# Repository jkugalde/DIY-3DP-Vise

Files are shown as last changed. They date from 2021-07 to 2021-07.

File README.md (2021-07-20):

# DIY 3DP Vise

[][cc-by-sa]

It is a small vise

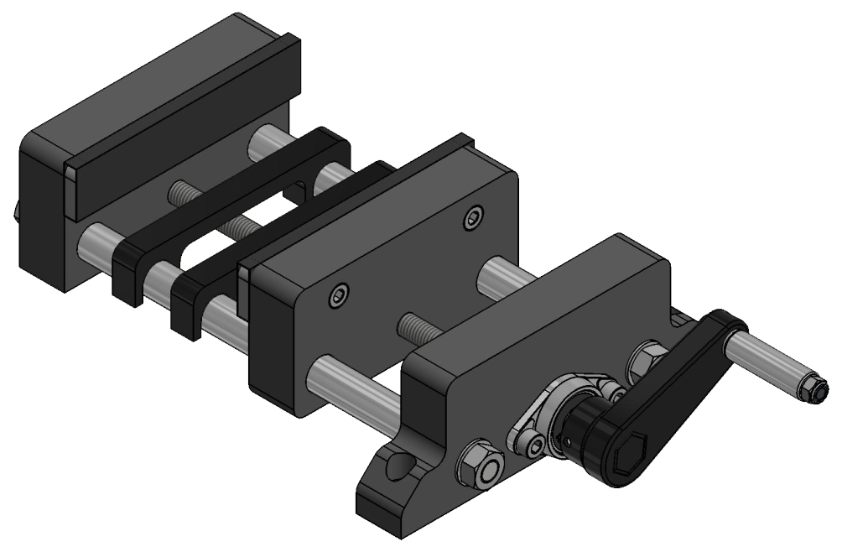
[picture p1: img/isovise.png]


## Features

- Cheap
- 115 mm opening
- Removable handle
- Fixed size, not affected by the movement of the jaw
- Rubber surface jaw

## How to build it

- [LIST](parts.md) of parts, pieces and tools. 
- [CAD files](parts/).
- [Assembly instructions](assembly.md)

## Future work

- A more comfortable handle, to fit the whole hand.
- Assembly guide with images.

# License

[][cc-by-sa]

This work is published under the license [Creative Commons Attribution 4.0 International
License][cc-by-sa].

[cc-by-sa]: https://creativecommons.org/licenses/by-sa/4.0/
[cc-by-sa-image]: https://i.creativecommons.org/l/by-sa/4.0/88x31.png
[cc-by-sa-shield]: https://img.shields.io/badge/License-CC%20BY%20SA%204.0-lightgrey.svg

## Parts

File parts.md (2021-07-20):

# Parts

## Commercial parts

 ITEM              | QTY
 ---------------------------   | ------------
 M8 threaded rod | 1 m (just to be sure)
  12.8 mm OD Aluminium tube | 1 m (just to be sure)
  M8 washer | 4
  M8 Nut | 5
  KFL08 bearing | 1
  M5x50 bolt | 1
  M5x20 parker bolts | 6
  M5 nut | 5
  M5 low profile nut | 4
  M5 locking nut | 1
  M5 washer | 2
  33 mm aluminium spacer | 1
  M3x6 set screw | 2
  M3 nut | 2
  Bike tube 700x18/23C | 1 

NOTES: 
- You can print the spacer (i put one in the .stls folder), i dont know where i got aluminium one that i used.
- If you cannot find low profile nuts, you can print the rubber plate2, which uses standard M5 nuts, but you will probably need a bigger bike tube.
- You can also replace the set screws with M3 not too long bolts.

## Printed parts

You can find the .step and .stl files in the [parts folder](parts/). 

 ITEM                   | Cantidad
 ---------------------------   | ------------
 Stationary Jaw | 1
 Stationary Jaw2 | 1
Mobile Jaw | 1
Rubber plate | 2
End-nut | 1
Crank | 1

   Print them sturdy and with low res.

## Tools

 ITEM |                  
 --------------------------- |  
 Scissors or cutter |
 1 mm allen wrench |
 4 mm allen wrench |
 Wrench (2) |
 Metal saw |

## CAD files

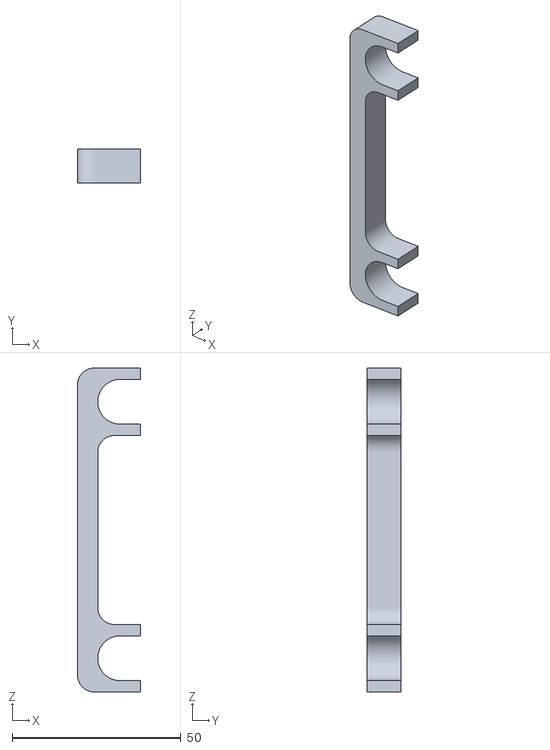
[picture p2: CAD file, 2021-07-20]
parts/STLs/Accessory flat surface.stl
18.6 x 10.0 x 96.0

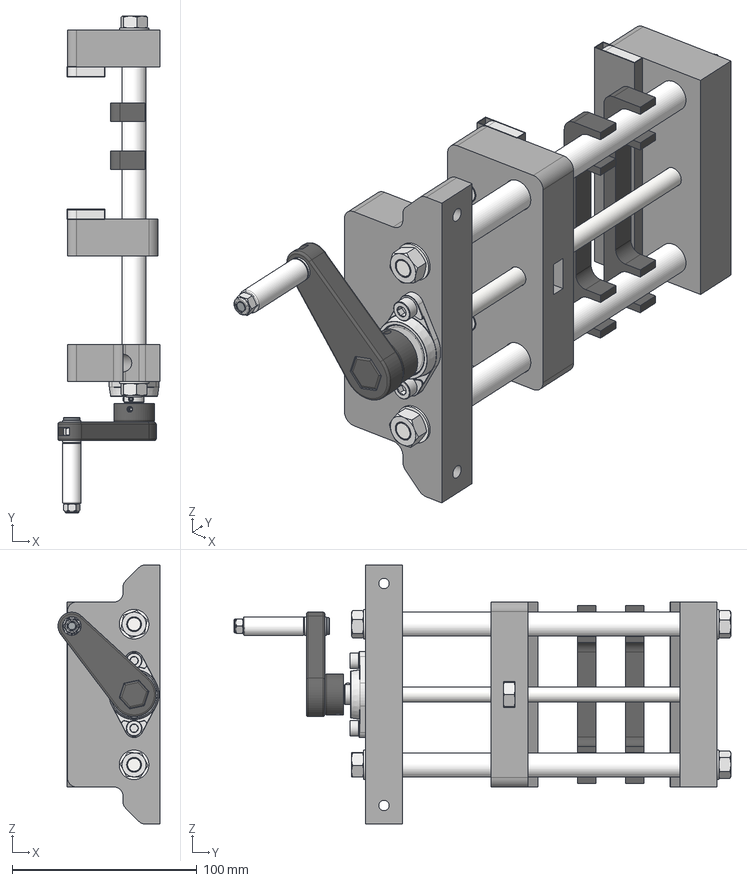
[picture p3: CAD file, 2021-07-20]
parts/Vise.stp
55.1 x 268.5 x 140.0 mm
Movingjaw
Stationaryjaw
AlumTube x 2
Stationaryjaw2
ThreadedRod x 2
M8Washer x 4
M8Nut x 5
KFL08
Rubberplate x 2
ThreadedRod_1
M5x20Bolt x 6
M5Nut x 4
Base x 2
M5Nut_1 x 3
Crank
EndNut
M3 nut x 2
Perno M5x8 cabeza plana
Espaciador 40mm
M5 washer small x 2
M5 Lock nut
RubberPiece x 2
PrisioneroM3 x 2

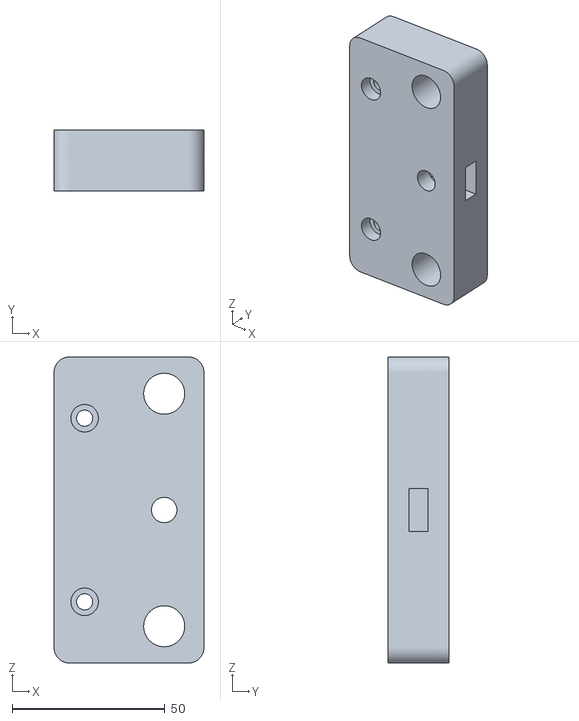
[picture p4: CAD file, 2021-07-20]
parts/STLs/Mobile Jaw.stl
49.0 x 20.0 x 100.0

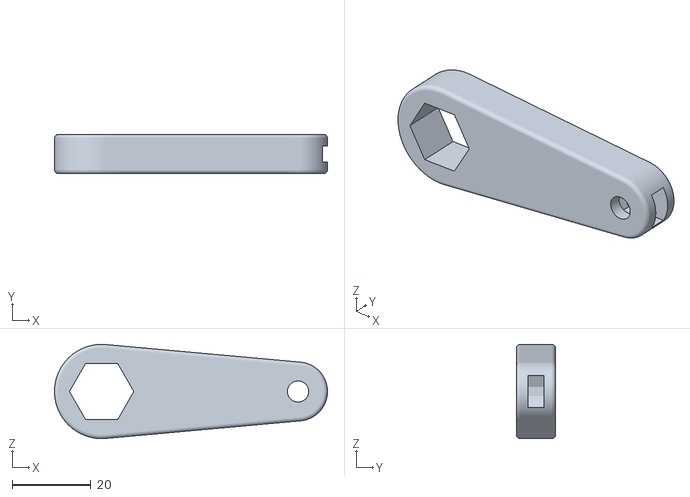
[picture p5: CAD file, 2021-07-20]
parts/STLs/Crank.stl
69.5 x 10.0 x 24.0

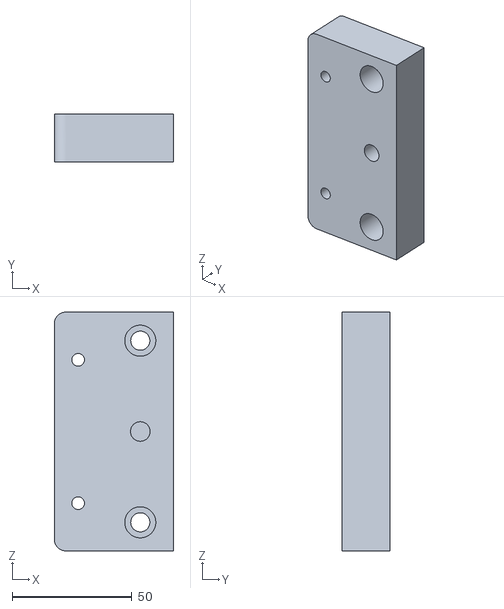
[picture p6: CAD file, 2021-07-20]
parts/STLs/Stationary Jaw.stl
50.0 x 20.0 x 100.0

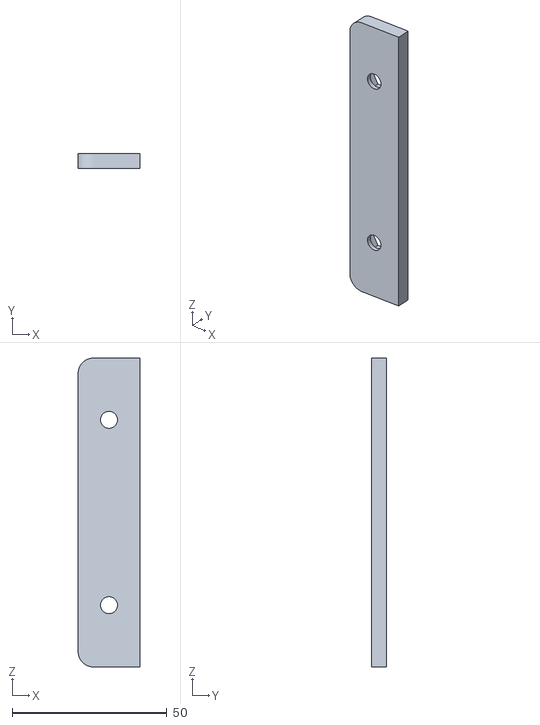
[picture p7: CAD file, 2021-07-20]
parts/STLs/Rubber plate.stl
20.0 x 5.00 x 100.0

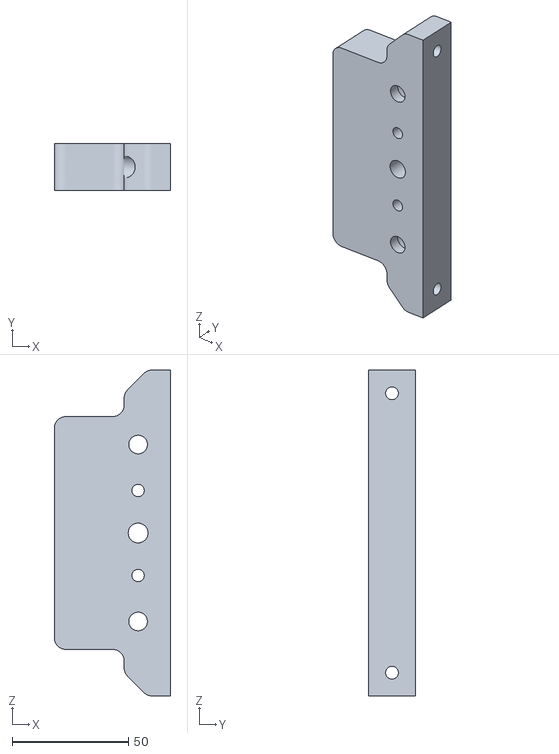
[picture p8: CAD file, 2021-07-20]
parts/STLs/Stationary Jaw2.stl
50.0 x 20.0 x 140.0

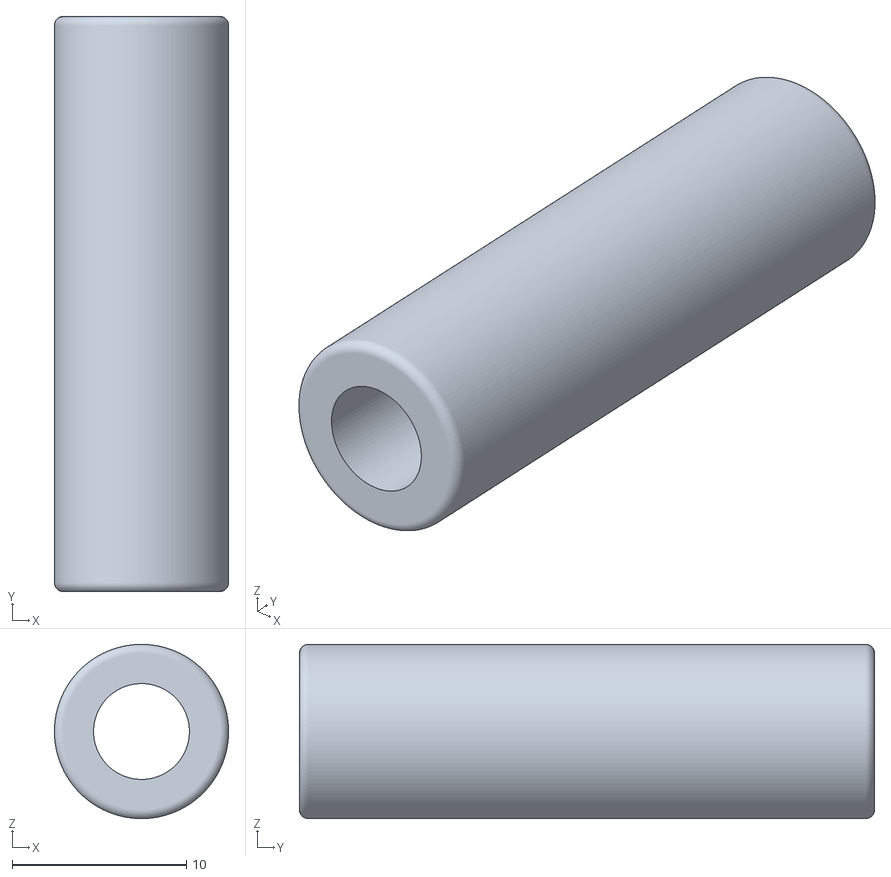
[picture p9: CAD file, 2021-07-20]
parts/STLs/PrintableSpacer.stl
10.0 x 33.0 x 10.00

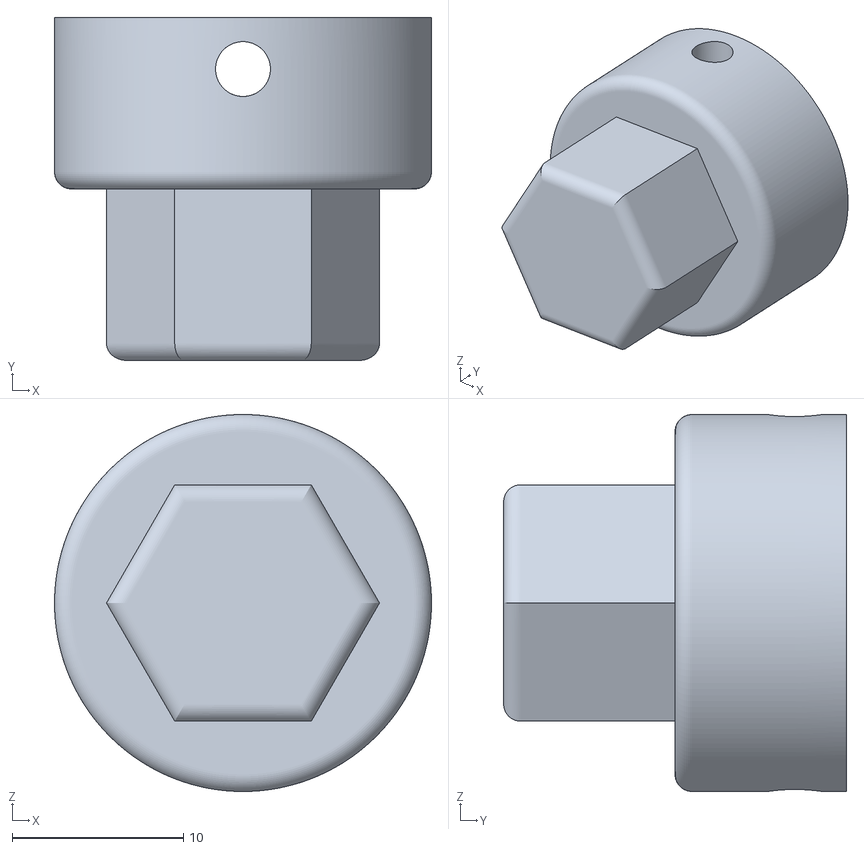
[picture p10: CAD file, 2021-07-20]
parts/STLs/End-Nut.stl
22.0 x 20.0 x 22.0

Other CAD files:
parts/Inventor Parts/Accessory flat surface.ipt
parts/Inventor Parts/Aluminium Tube.ipt
parts/Inventor Parts/Crank.ipt
parts/Inventor Parts/End-Nut.ipt
parts/Inventor Parts/KFL08 Bearing.ipt
parts/Inventor Parts/M3 nut.ipt
parts/Inventor Parts/M3x6 Set Screw.ipt
parts/Inventor Parts/M5 Lock nut.ipt
parts/Inventor Parts/M5 Low profile Nut.ipt
parts/Inventor Parts/M5 Nut.ipt
parts/Inventor Parts/M5 Washer.ipt
parts/Inventor Parts/M5x20 Bolt.ipt
parts/Inventor Parts/M5x50 Bolt.ipt
parts/Inventor Parts/M8 Nut.ipt
parts/Inventor Parts/M8 Washer.ipt
parts/Inventor Parts/Mobile Jaw.ipt
parts/Inventor Parts/Rubber plate.ipt
parts/Inventor Parts/Rubber plate2.ipt
parts/Inventor Parts/RubberPiece.ipt
parts/Inventor Parts/Spacer.ipt
parts/Inventor Parts/Stationary Jaw.ipt
parts/Inventor Parts/Stationary Jaw2.ipt
parts/Inventor Parts/Threaded Rod 200mm.ipt
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

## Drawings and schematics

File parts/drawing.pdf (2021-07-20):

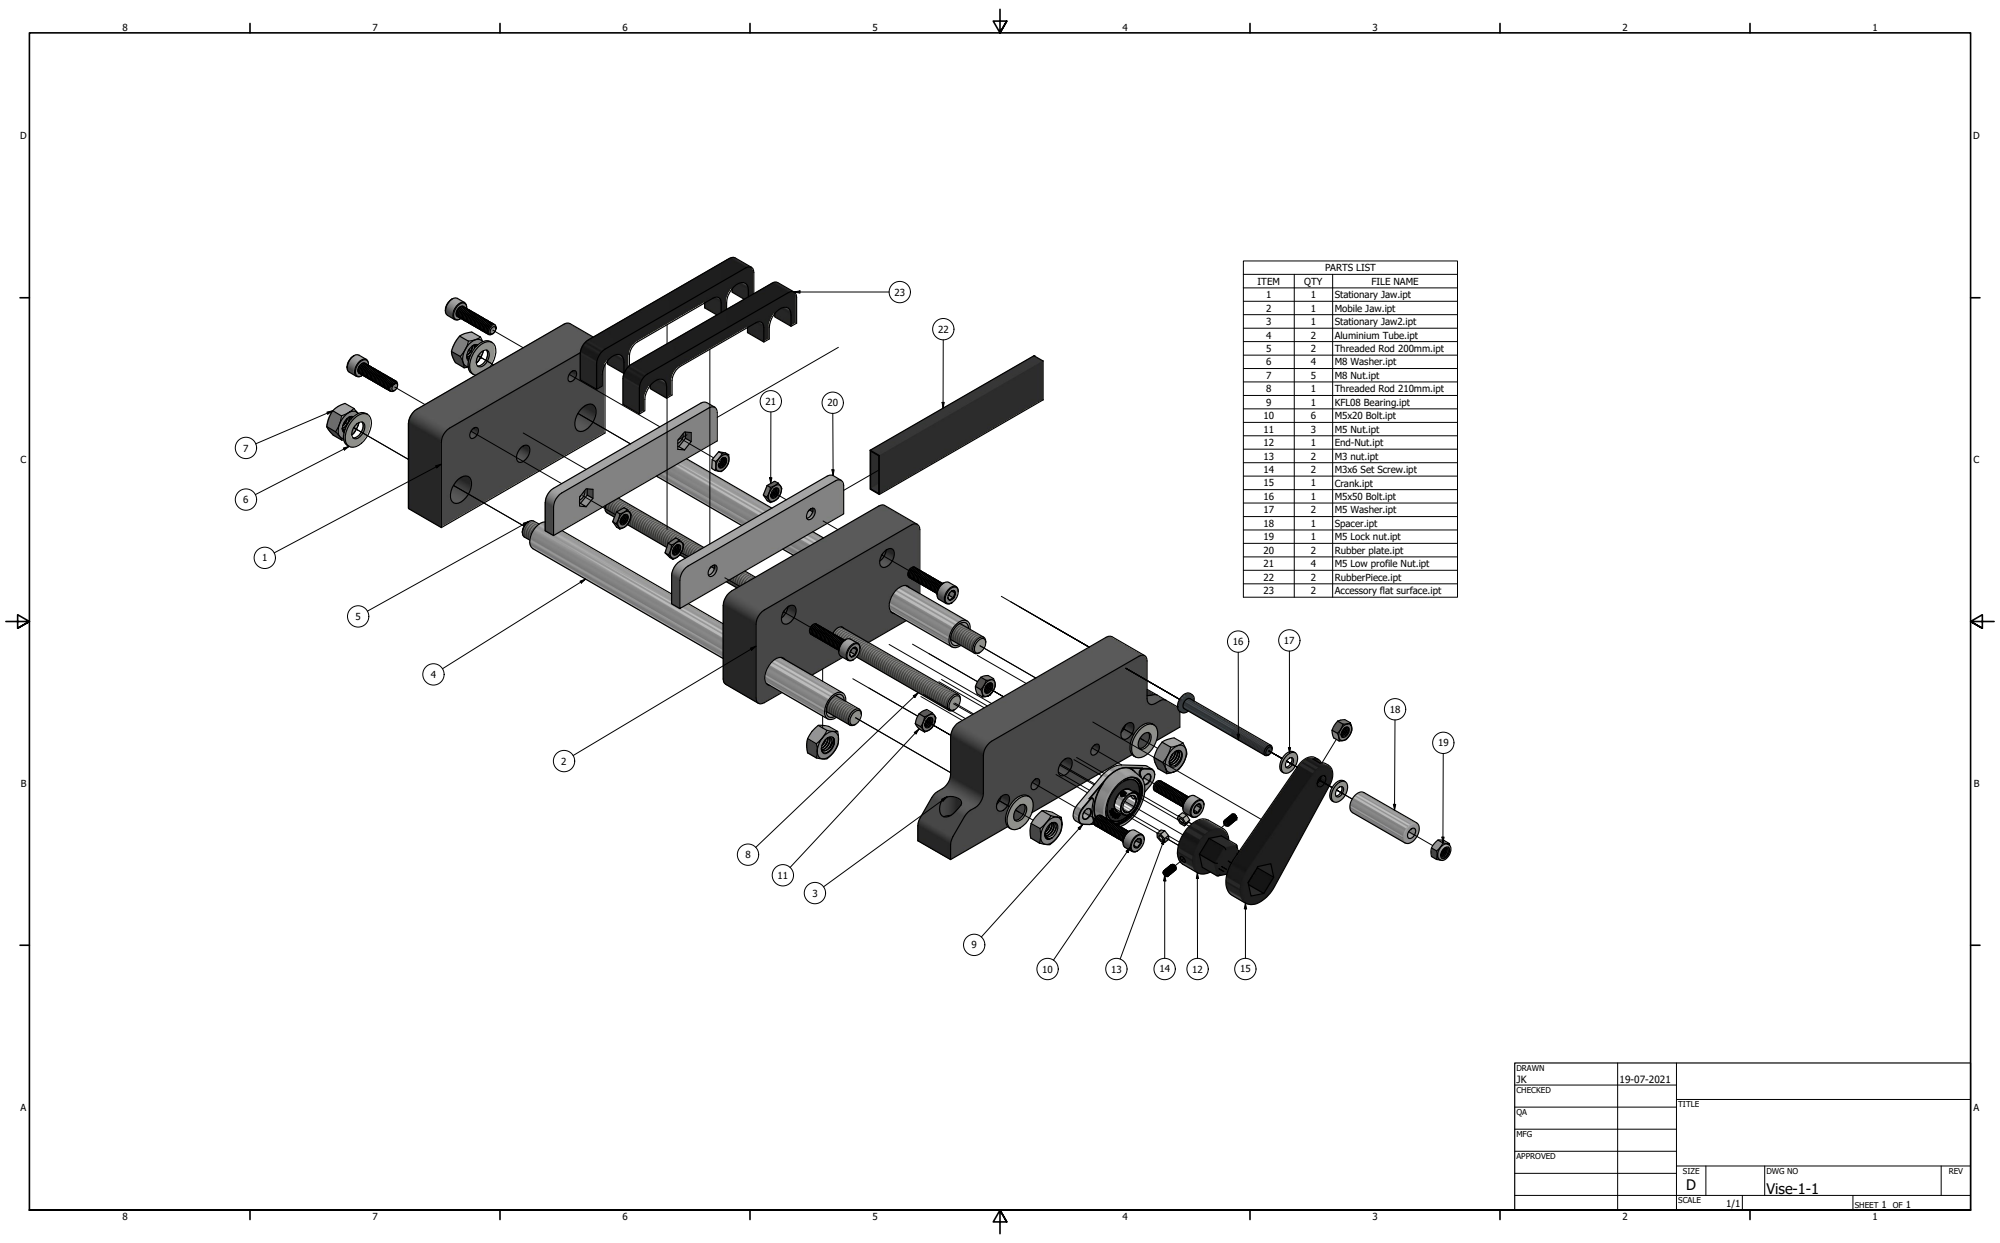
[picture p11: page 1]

I T E M | Q TY | F I L E N A M E
1 | 1 | S t a t i o n a r y J a w . i p t
2 | 1 | M o b ile J a w . i p t
3 | 1 | S t a t i o n a r y J a w 2 . i p t
4 | 2 | Alu m i n i u m T u b e . i p t
5 | 2 | T h r e a d e d R o d 2 0 0 m m . i p t
6 | 4 | M 8 W a s h e r . i p t
7 | 5 | M 8 N u t . i p t
8 | 1 | T h r e a d e d R o d 2 1 0 m m . i p t
9 | 1 | K F L 0 8 B e a r i n g . i p t
1 0 | 6 | M 5 x 2 0 B olt . i p t
1 1 | 3 | M 5 N u t . i p t
1 2 | 1 | E n d -N u t . i p t
1 3 | 2 | M 3 n u t . i p t
1 4 | 2 | M 3 x 6 S e t S c r e w . i p t
1 5 | 1 | C r a n k . i p t
1 6 | 1 | M 5 x 5 0 B olt . i p t
1 7 | 2 | M 5 W a s h e r . i p t
1 8 | 1 | S p a c e r . i p t
1 9 | 1 | M 5 L o c k n u t . i p t
2 0 | 2 | R u b b e r pla t e . i p t
2 1 | 4 | M 5 L o w p r o f ile N u t . i p t
2 2 | 2 | R u b b e r P i e c e . i p t
2 3 | 2 | A c c e s s o r y fla t s u r fa c e . i p t

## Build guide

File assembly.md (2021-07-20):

# Asssembly guide

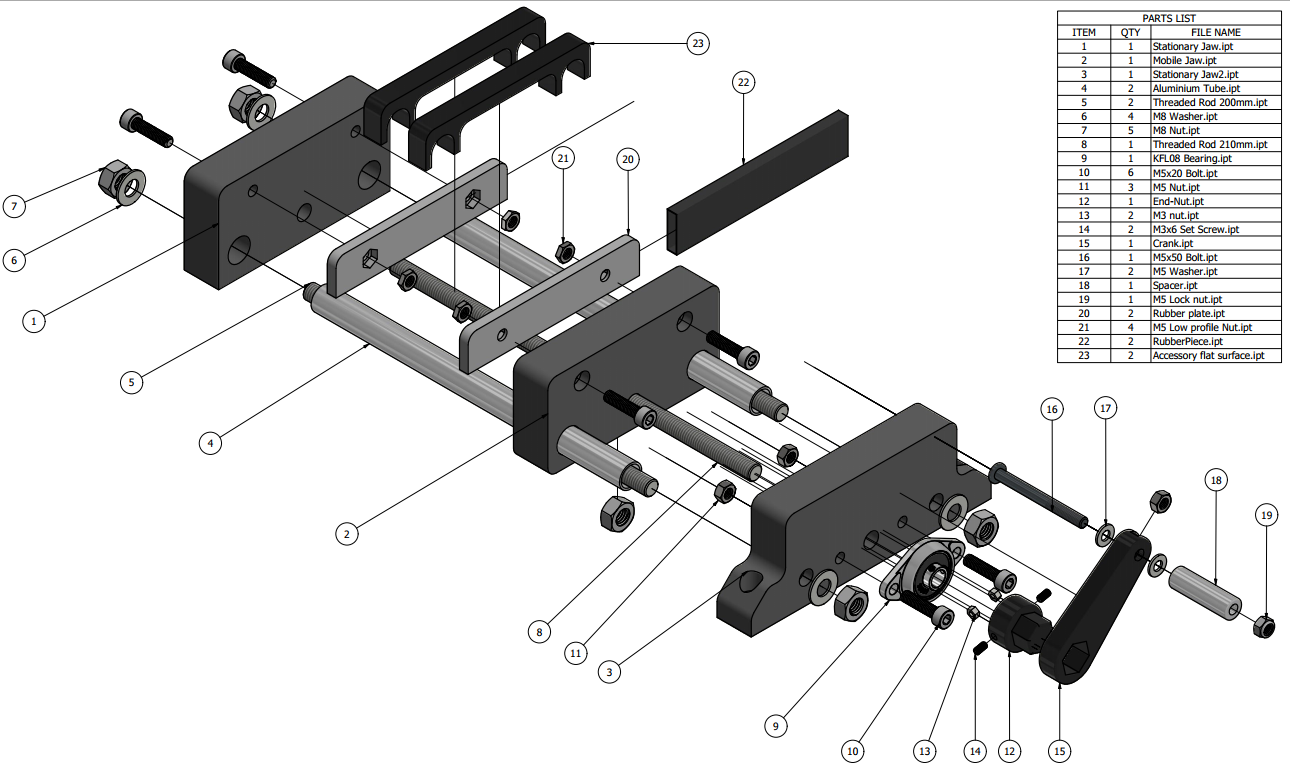
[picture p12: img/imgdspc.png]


If this image is too small, the pdf is [here](/parts/drawing.pdf).

## Preparing parts

- You need 3 pieces of M8 threaded rod to fit as the model implies, approximately, two 200 mm bars and one 210 mm bar, but it can be whatever you want while it matches with the aluminium tubes, which are 180 mm by default. You can cut these pieces with a saw and a... 

...vise. *wink wink*

- Cut two 100 mm long pieces of the rubber tube, using a cutter or scissors. Make two holes that match with the rubber plate holes(20) using pliers in one of the sides of the rubber pieces, so the M5 bolts can pass through them.

## Step by step

- Pass the aluminium bars(4) through the holes in the mobile jaw(2) and fit the ends in the stationary jaws(1)(3).
- Pass the threaded rods(5) through the aluminium tubes. Put a M8 washer(6) and nut(7) in each of the ends and squeeze with the wrenchs (not too much).
- Put a M8 nut inside the mobile jaw, by the bottom hole.
- Pass the threaded rod(8) through the central hole in the jaws and the M8 nut. The end must be barely touching the stationary jaw(1).
- Put the bearing(9) in the threaded rod, bolt it with m5x20 bolts(10) and M5 nuts(11) using the 4 mm allen wrench, which are placed in the other face of the stationary jaw(3)
- Pass two M3 nuts(13) through the holes in the end nut(12), and the M3x6 set screws(14) through them.
- Put the end-nut in the free end of the threaded rod and tighten the set screws with the 1 mm allen wrench.
- Get the crank(15) and put a M5 nut in the smaller end.
- Pass the M5x50 flat head bolt(16) through the nut, with M5 washers(17) in both sides.
- Put the spacer and the lock nut in the bolt. The spacer must spin freely.
- Put the M5 low profile nuts(21) in the holes of the rubber plates(22).
- Wrap the rubber plates with the rubber pieces, the holes must match.
- Bolt the rubber plates in the stationary jaw(1) and the mobile jaw(2) using M5x20 bolts and the 4 mm allen wrench.

- READY!

Then you can bolt the vise using the holes in the stationary jaw(3), and start using it putting the crank in the end nut.

The accesory flat surface is not mandatory, you can use it as a base to support pieces.

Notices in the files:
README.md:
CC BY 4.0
